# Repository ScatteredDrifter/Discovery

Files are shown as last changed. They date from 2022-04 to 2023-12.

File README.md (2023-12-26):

# Discovery

A bluetooth unibody splitkeyboard

---

### Current Status:

- PCB might be conceptualized soon

---

Discovery was yet another spaceshuttle flewn by NASA for their supply and repair schedules surrounding the orbit and ISS.  

---

## Features:
- Layout:
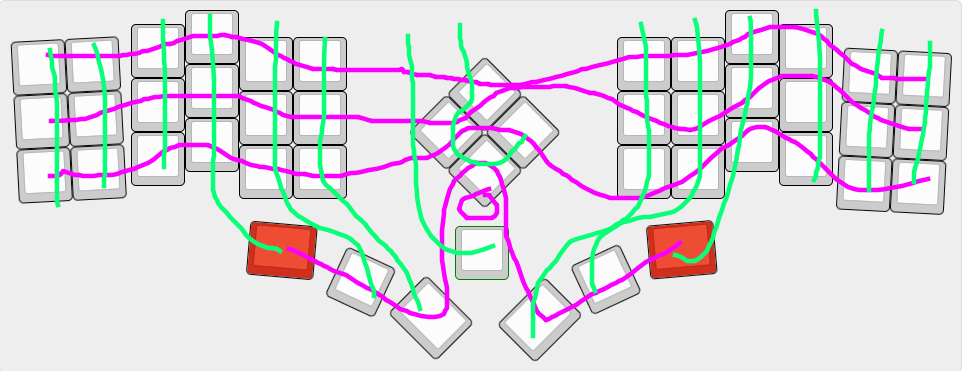
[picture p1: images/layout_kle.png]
Image of layout by KLE


---

## Images:

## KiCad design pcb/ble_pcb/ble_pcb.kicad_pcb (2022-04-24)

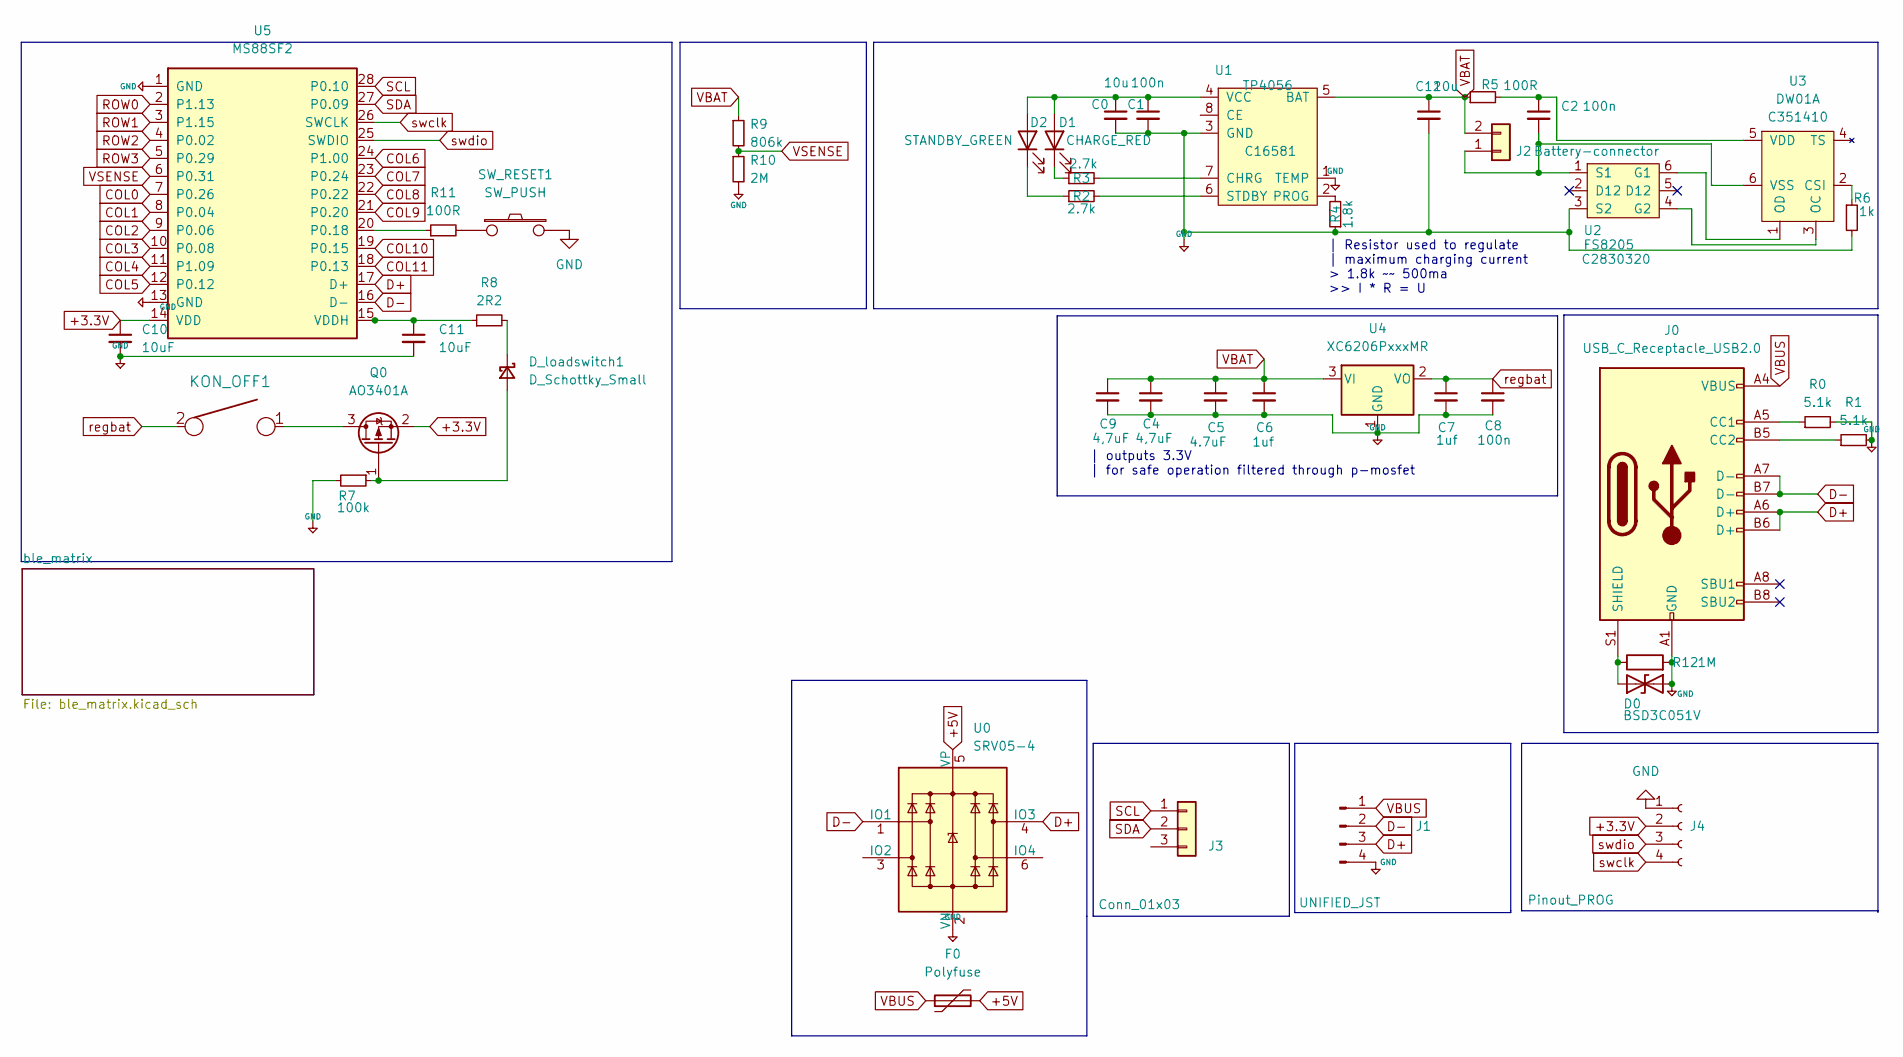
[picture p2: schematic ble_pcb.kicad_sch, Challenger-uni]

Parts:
C0, C12: 10u; C_0805_2012Metric; LCSC C15850
C1, C2, C8: 100n; C_0805_2012Metric; LCSC C49678
C4, C9: 4,7uF; C_0805_2012Metric; LCSC C1779
C5: 4.7uF; C_0805_2012Metric; LCSC C1779
C6, C7: 1uf; C_0805_2012Metric; LCSC C28323
C10, C11: 10uF; C_0805_2012Metric; LCSC C15850
D0: BSD3C051V; D_DO-201AE_P15.24mm_Horizontal; LCSC C151996
D1: CHARGE_RED; D_0805_2012Metric; LCSC C84256
D2: STANDBY_GREEN; D_0805_2012Metric; LCSC C2297
D_loadswitch1: D_Schottky_Small; D_SOD-323_HandSoldering; LCSC C172430
F0: Polyfuse; Fuse_0603_1608Metric; LCSC C69688
J0: USB_C_Receptacle_USB2.0; USB_C_Receptacle_HRO_TYPE-C-31-M-12; LCSC C165948
J1: UNIFIED_JST; Aio3_jst; LCSC C2845363
J2: Battery-connector; Molex PicoBlade 2Pin smt tht
J3: Conn_01x03; PinHeader_1x04_P2.54mm_Vertical
J4: Pinout_PROG; PinHeader_1x04_P2.54mm_Vertical
KON_OFF1: KEYSW; K3-2380S-E1 On-on
Q0: AO3401A; SOT-23; LCSC C15127
R0, R1: 5.1k; R_0815_2038Metric; LCSC C27834
R2, R3: 2.7k; R_0815_2038Metric; LCSC C2907305
R4: 1.8k; R_0815_2038Metric; LCSC C2907292
R5, R11: 100R; R_0815_2038Metric; LCSC C17408
R6: 1k; R_0815_2038Metric; LCSC C17513
R7: 100k; R_0815_2038Metric; LCSC C149504
R8: 2R2; R_0815_2038Metric; LCSC C17521
R9: 806k; R_0815_2038Metric; LCSC C63494
R10: 2M; R_0815_2038Metric; LCSC C26112
R12: 1M; R_0815_2038Metric; LCSC C17514
SW_RESET1: SW_PUSH; SW_SPST_TL3342; LCSC C318884
U0: SRV05-4; SOT-23-6; LCSC C85364
U1: TP4056; TP4056_SOP-8-PP; LCSC C16581
U2: FS8205; SOT-23-6; LCSC C2830320
U3: DW01A; SOT-23-6; LCSC C351410
U4: XC6206PxxxMR; SOT-23; LCSC C5446
U5: MS88SF2

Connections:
+3.3V: C10.1, J4.2, Q0.2 (S), U5.14 (VDD)
COL0: U5.7 (P0.26); also elsewhere on the board
COL1: U5.8 (P0.04); also elsewhere on the board
COL2: U5.9 (P0.06); also elsewhere on the board
COL3: U5.10 (P0.08); also elsewhere on the board
COL4: U5.11 (P1.09); also elsewhere on the board
COL5: U5.12 (P0.12); also elsewhere on the board
COL6: U5.24 (P1.00); also elsewhere on the board
COL7: U5.23 (P0.24); also elsewhere on the board
COL8: U5.22 (P0.22); also elsewhere on the board
COL9: U5.21 (P0.20); also elsewhere on the board
COL10: U5.19 (P0.15); also elsewhere on the board
COL11: U5.18 (P0.13); also elsewhere on the board
D+: J0.A6 (D+), J0.B6 (D+), J1.3, U0.4 (IO3), U5.17 (D+)
D-: J0.A7 (D-), J0.B7 (D-), J1.2, U0.1 (IO1), U5.16 (D-)
unnamed: C0.1, C1.1, D1.2 (A), D2.2 (A), U1.4 (VCC)
unnamed: C2.1, R5.2, U3.5 (VDD)
unnamed: C2.2, J2.1, U2.1 (S1), U3.6 (VSS)
unnamed: C4.1, C5.1, C6.1, C9.1, U4.3 (VI)
unnamed: C11.1, R8.1, U5.15 (VDDH)
unnamed: D0.1 (A1), J0.S1 (SHIELD), R12.1
unnamed: D1.1 (K), R3.1
unnamed: D2.1 (K), R2.1
unnamed: D_loadswitch1.1 (K), R8.2
unnamed: D_loadswitch1.2 (A), Q0.1 (G), R7.1
unnamed: J0.A5 (CC1), R0.1
unnamed: J0.B5 (CC2), R1.1
unnamed: KON_OFF1.1, Q0.3 (D)
unnamed: R2.2, U1.6 (STDBY)
unnamed: R3.2, U1.7 (CHRG)
unnamed: R4.2, U1.2 (PROG)
unnamed: R6.1, U3.2 (CSI)
unnamed: R11.1, U5.20 (P0.18)
unnamed: R11.2, SW_RESET1.1
unnamed: U2.4 (G2), U3.3 (OC)
unnamed: U2.6 (G1), U3.1 (OD)
ROW0: U5.2 (P1.13); also elsewhere on the board
ROW1: U5.3 (P1.15); also elsewhere on the board
ROW2: U5.4 (P0.02); also elsewhere on the board
ROW3: U5.5 (P0.29); also elsewhere on the board
SCL: J3.1, U5.28 (P0.10)
SDA: J3.2, U5.27 (P0.09)
VBAT: C12.1, J2.2, R5.1, R9.1, U1.5 (BAT)
VBUS: F0.1, J0.A4 (VBUS), J0.A9 (VBUS), J0.B4 (VBUS), J0.B9 (VBUS), J1.1
VSENSE: R9.2, R10.1, U5.6 (P0.31)
regbat: C7.1, C8.1, KON_OFF1.2, U4.2 (VO)
swclk: J4.4, U5.26 (SWCLK)
swdio: J4.3, U5.25 (SWDIO)

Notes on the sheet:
| outputs 3.3V | for safe operation filtered through p-mosfet
| Resistor used to regulate | maximum charging current > 1.8k ~~ 500ma >> I * R = U

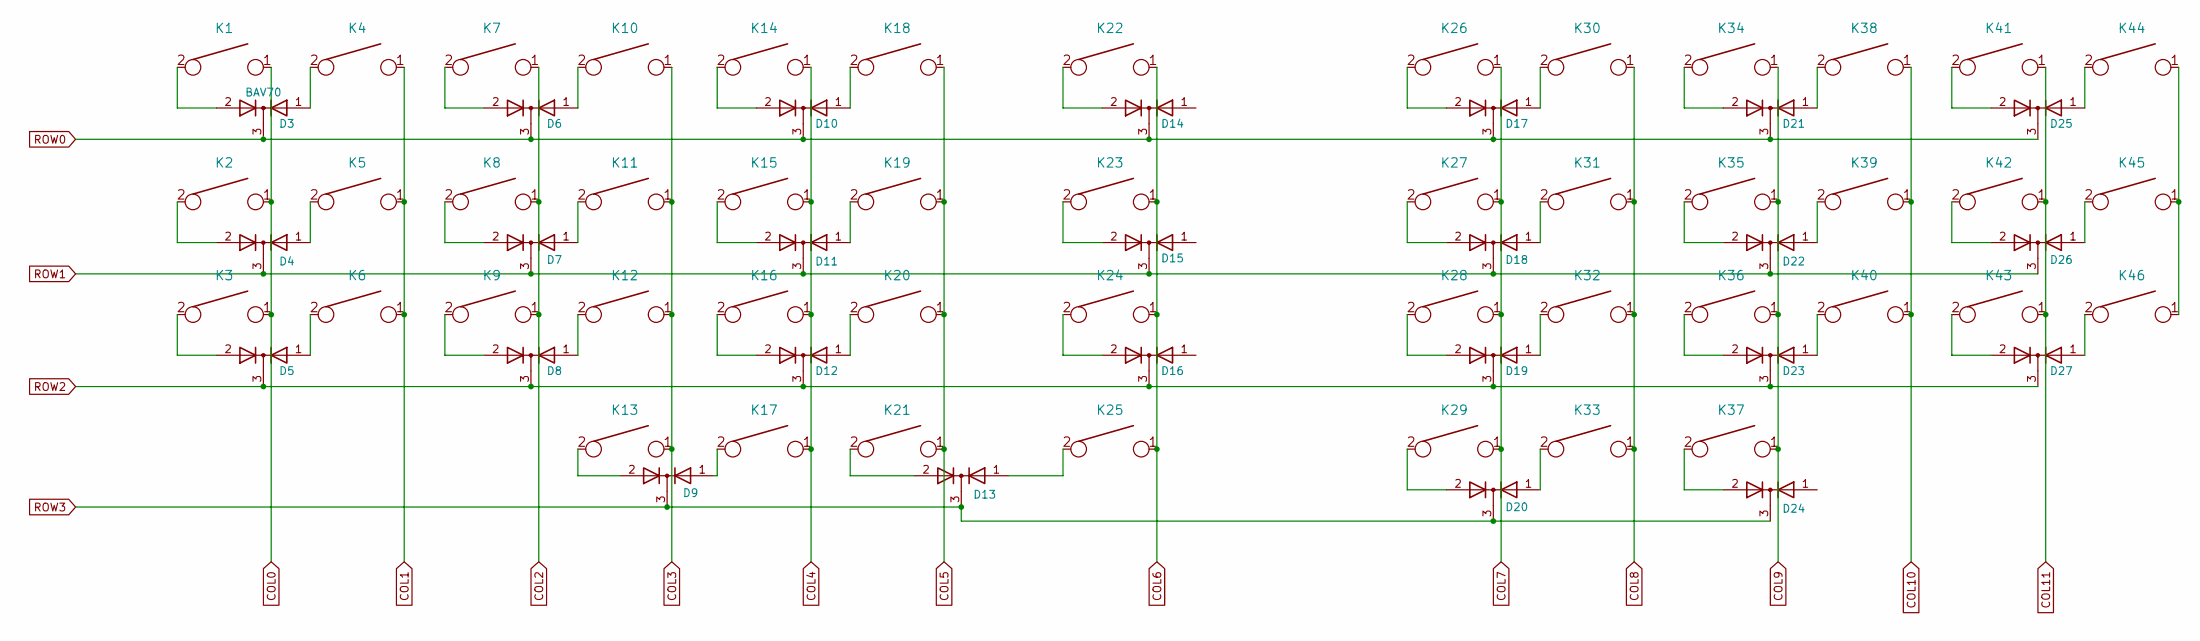
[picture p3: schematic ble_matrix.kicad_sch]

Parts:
D3: BAV70; SOT-23
D4, D5, D6, D7, D8, D9, D10, D11, D12, D13, D14, D15, D16, D17, D18, D19, D20, D21, D22, D23, D24, D25, D26, D27: (no value)
K1: KEYSW
K2, K3, K4, K5, K6, K7, K8, K9, K10, K11, K12, K13, K14, K15, K16, K17, K18, K19, K20, K21, K22, K23, K24, K25, K26, K27, K28, K29, K30, K31, K32, K33, K34, K35, K36, K37, K38, K39, K40, K41, K42, K43, K44, K45, K46: (no value)

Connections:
COL0: K1.1, K2.1, K3.1; also elsewhere on the board
COL1: K4.1, K5.1, K6.1; also elsewhere on the board
COL2: K7.1, K8.1, K9.1; also elsewhere on the board
COL3: K10.1, K11.1, K12.1, K13.1; also elsewhere on the board
COL4: K14.1, K15.1, K16.1, K17.1; also elsewhere on the board
COL5: K18.1, K19.1, K20.1, K21.1; also elsewhere on the board
COL6: K22.1, K23.1, K24.1, K25.1; also elsewhere on the board
COL7: K26.1, K27.1, K28.1, K29.1; also elsewhere on the board
COL8: K30.1, K31.1, K32.1, K33.1; also elsewhere on the board
COL9: K34.1, K35.1, K36.1, K37.1; also elsewhere on the board
COL10: K38.1, K39.1, K40.1; also elsewhere on the board
COL11: K41.1, K42.1, K43.1; also elsewhere on the board
unnamed: D3.1 (A), K4.2
unnamed: D3.2 (A), K1.2
unnamed: D4.1 (A), K5.2
unnamed: D4.2 (A), K2.2
unnamed: D5.1 (A), K6.2
unnamed: D5.2 (A), K3.2
unnamed: D6.1 (A), K10.2
unnamed: D6.2 (A), K7.2
unnamed: D7.1 (A), K11.2
unnamed: D7.2 (A), K8.2
unnamed: D8.1 (A), K12.2
unnamed: D8.2 (A), K9.2
unnamed: D9.1 (A), K17.2
unnamed: D9.2 (A), K13.2
unnamed: D10.1 (A), K18.2
unnamed: D10.2 (A), K14.2
unnamed: D11.1 (A), K19.2
unnamed: D11.2 (A), K15.2
unnamed: D12.1 (A), K20.2
unnamed: D12.2 (A), K16.2
unnamed: D13.1 (A), K25.2
unnamed: D13.2 (A), K21.2
unnamed: D14.2 (A), K22.2
unnamed: D15.2 (A), K23.2
unnamed: D16.2 (A), K24.2
unnamed: D17.1 (A), K30.2
unnamed: D17.2 (A), K26.2
unnamed: D18.1 (A), K31.2
unnamed: D18.2 (A), K27.2
unnamed: D19.1 (A), K32.2
unnamed: D19.2 (A), K28.2
unnamed: D20.1 (A), K33.2
unnamed: D20.2 (A), K29.2
unnamed: D21.1 (A), K38.2
unnamed: D21.2 (A), K34.2
unnamed: D22.1 (A), K39.2
unnamed: D22.2 (A), K35.2
unnamed: D23.1 (A), K40.2
unnamed: D23.2 (A), K36.2
unnamed: D24.2 (A), K37.2
unnamed: D25.1 (A), K44.2
unnamed: D25.2 (A), K41.2
unnamed: D26.1 (A), K45.2
unnamed: D26.2 (A), K42.2
unnamed: D27.1 (A), K46.2
unnamed: D27.2 (A), K43.2
unnamed: K44.1, K45.1, K46.1
ROW0: D3.3 (K), D6.3 (K), D10.3 (K), D14.3 (K), D17.3 (K), D21.3 (K), D25.3 (K); also elsewhere on the board
ROW1: D4.3 (K), D7.3 (K), D11.3 (K), D15.3 (K), D18.3 (K), D22.3 (K), D26.3 (K); also elsewhere on the board
ROW2: D5.3 (K), D8.3 (K), D12.3 (K), D16.3 (K), D19.3 (K), D23.3 (K), D27.3 (K); also elsewhere on the board
ROW3: D9.3 (K), D13.3 (K), D20.3 (K), D24.3 (K); also elsewhere on the board

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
Board: 2 copper layers, 115 parts (0 on the bottom side), 97 nets, no tracks yet.
